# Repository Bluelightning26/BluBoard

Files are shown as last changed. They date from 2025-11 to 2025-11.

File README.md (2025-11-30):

# BluBoard
## A custom 75% keyboard!

### Key features: 
- MacOs Layout, 75% & separated arrow keys
- Two Rotary Encoders w/ Switches (Brightness + Volume)
- Cherry MX Brown Switches
- Simple Case with plop in design that keeps the black PCB visible while protecting the bottom and sides
- Specific parts used are documented in [BOM.md](BOM.md)

## Renders!!











### What I'd do differently next time
There were several sacrifices I had to make in the name of budgeting. Also, since this is my first full keyboard, I didn't want to overwhelm myself in the build process and avoided things that are difficult to solder. I am planning on making a v2 version of this keyboard after a few months of use, learning from the probable mistakes I made in design along the way

Nice features this would have:
- Wireless capability, BT + Dongle
- Acrylic Case
- RGB Backlit Keys
- 
(To be added to during build process along with when I use the board!)

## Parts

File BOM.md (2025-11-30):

| Item | Quantity | Total Cost | Link |
|---|---|---|---|
| Cherry MX Brown Switches | 90 | 31.61 | https://www.aliexpress.us/item/3256808812099705.html |
| Stabilizers | 4 + 1 | 3.55 | https://www.aliexpress.us/item/3256809701679392.html |
| Pi Pico 2 + Micro USB Cable | 1 | 14.99 | https://www.amazon.com/gp/product/B0F4W9J5CC/ |
| Rotary Encoder | 3 | 0.99 | https://www.aliexpress.us/item/3256807457768762.html |
| PCB | 1 | 57.49 | - |
| Case | 1 | - | - |
| Keycaps | - | 35.99 | https://www.amazon.com/gp/product/B0BVYQ7GQS/ |
| **Total inc shipping + tariffs:** | | **144.62** | |

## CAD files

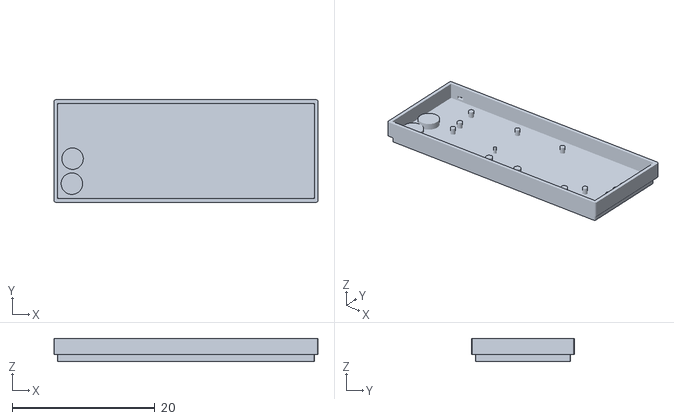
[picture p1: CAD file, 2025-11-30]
CAD/BluBoardCase.stl
37.0 x 14.4 x 3.25

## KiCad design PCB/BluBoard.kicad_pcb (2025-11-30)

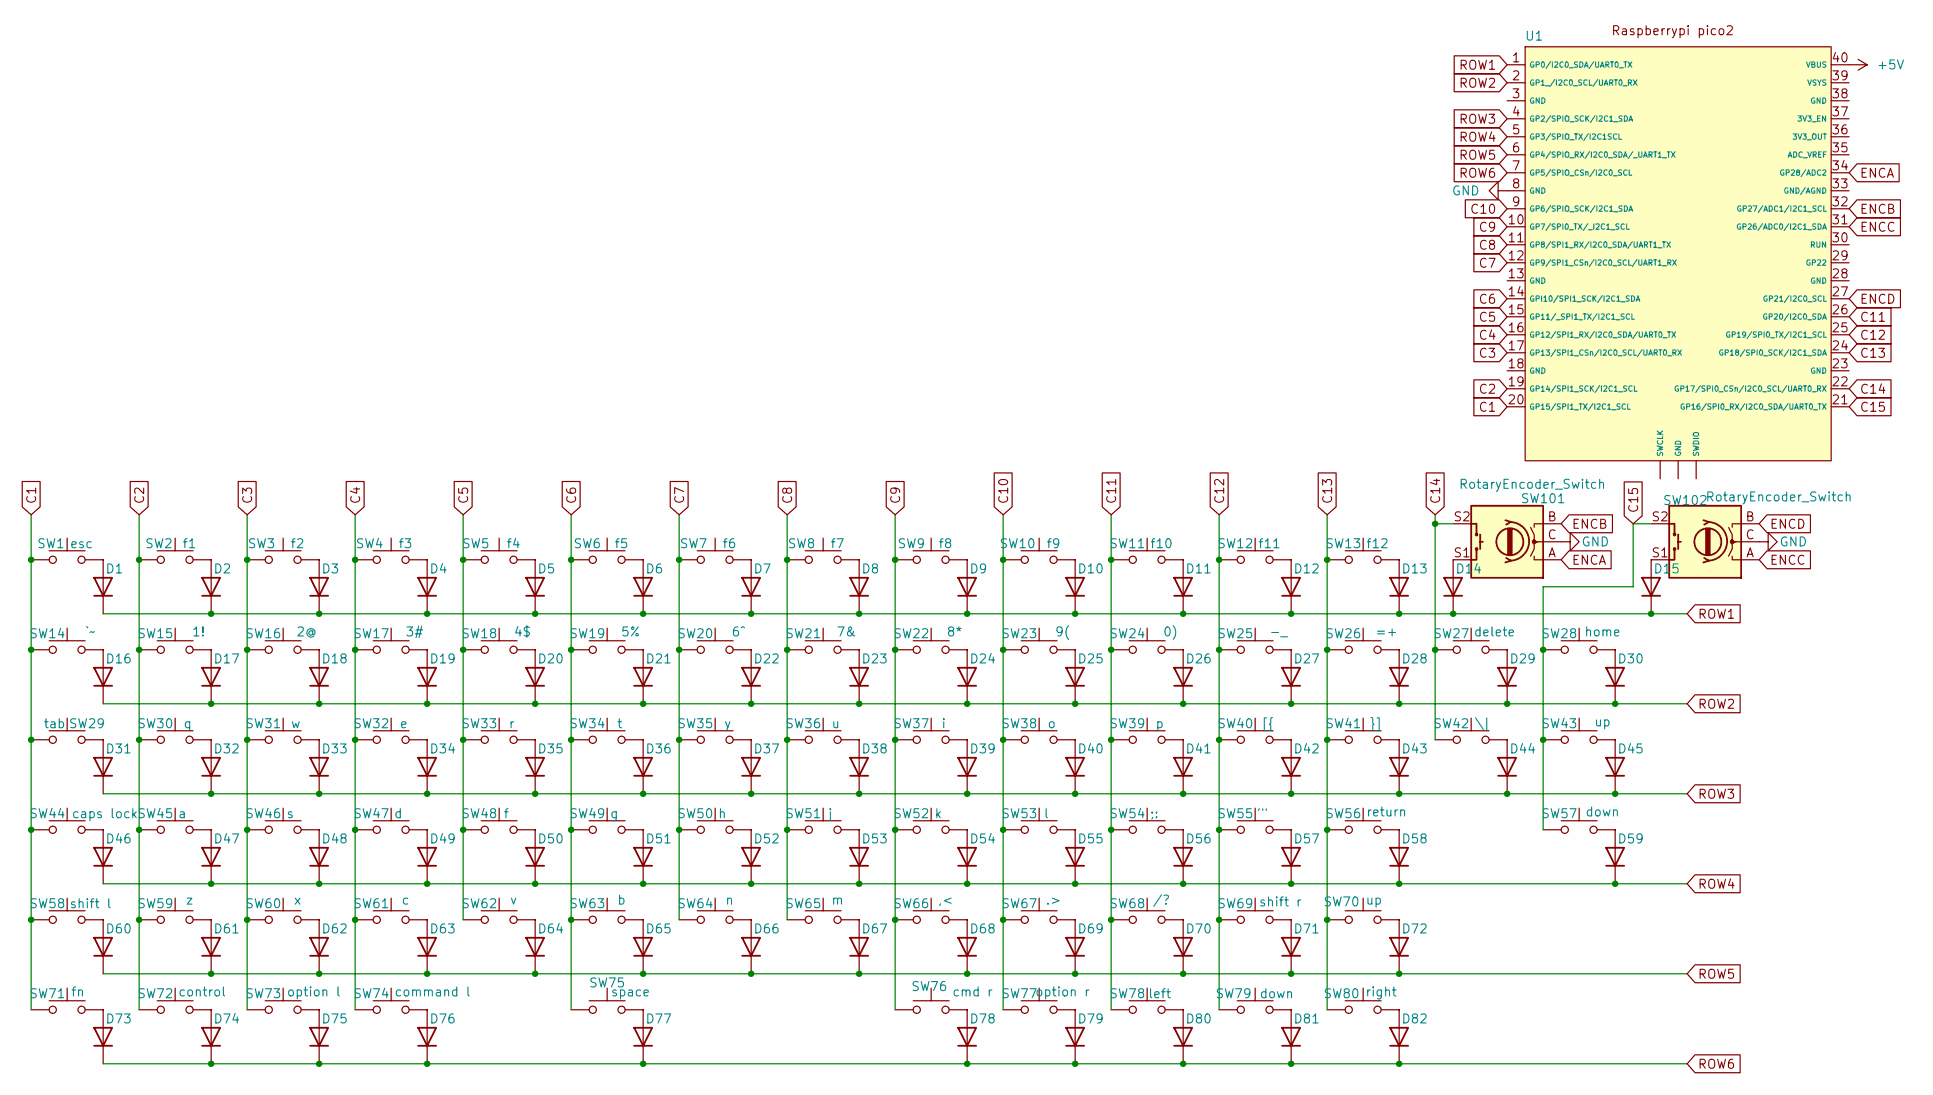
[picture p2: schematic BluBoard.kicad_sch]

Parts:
D1, D2, D3, D4, D5, D6, D7, D8, D9, D10, D11, D12, D13, D14, D15, D16, D17, D18, D19, D20, D21, D22, D23, D24, D25, D26, D27, D28, D29, D30, D31, D32, D33, D34, D35, D36, D37, D38, D39, D40, D41, D42, D43, D44, D45, D46, D47, D48, D49, D50, D51, D52, D53, D54, D55, D56, D57, D58, D59, D60, D61, D62, D63, D64, D65, D66, D67, D68, D69, D70, D71, D72, D73, D74, D75, D76, D77, D78, D79, D80, D81, D82: D; D_DO-35_SOD27_P7.62mm_Horizontal
SW1: esc; SW_Cherry_MX_1.00u_PCB
SW2: f1; SW_Cherry_MX_1.00u_PCB
SW3: f2; SW_Cherry_MX_1.00u_PCB
SW4: f3; SW_Cherry_MX_1.00u_PCB
SW5: f4; SW_Cherry_MX_1.00u_PCB
SW6: f5; SW_Cherry_MX_1.00u_PCB
SW7: f6; SW_Cherry_MX_1.00u_PCB
SW8: f7; SW_Cherry_MX_1.00u_PCB
SW9: f8; SW_Cherry_MX_1.00u_PCB
SW10: f9; SW_Cherry_MX_1.00u_PCB
SW11: f10; SW_Cherry_MX_1.00u_PCB
SW12: f11; SW_Cherry_MX_1.00u_PCB
SW13: f12; SW_Cherry_MX_1.00u_PCB
SW14: `~; SW_Cherry_MX_1.00u_PCB
SW15: 1!; SW_Cherry_MX_1.00u_PCB
SW16: 2@; SW_Cherry_MX_1.00u_PCB
SW17: 3#; SW_Cherry_MX_1.00u_PCB
SW18: 4$; SW_Cherry_MX_1.00u_PCB
SW19: 5%; SW_Cherry_MX_1.00u_PCB
SW20: 6^; SW_Cherry_MX_1.00u_PCB
SW21: 7&; SW_Cherry_MX_1.00u_PCB
SW22: 8*; SW_Cherry_MX_1.00u_PCB
SW23: 9(; SW_Cherry_MX_1.00u_PCB
SW24: 0); SW_Cherry_MX_1.00u_PCB
SW25: -_; SW_Cherry_MX_1.00u_PCB
SW26: =+; SW_Cherry_MX_1.00u_PCB
SW27: delete; SW_Cherry_MX_2.00u_PCB
SW28: home; SW_Cherry_MX_1.00u_PCB
SW29: tab; SW_Cherry_MX_1.50u_PCB
SW30: q; SW_Cherry_MX_1.00u_PCB
SW31: w; SW_Cherry_MX_1.00u_PCB
SW32: e; SW_Cherry_MX_1.00u_PCB
SW33: r; SW_Cherry_MX_1.00u_PCB
SW34: t; SW_Cherry_MX_1.00u_PCB
SW35: y; SW_Cherry_MX_1.00u_PCB
SW36: u; SW_Cherry_MX_1.00u_PCB
SW37: i; SW_Cherry_MX_1.00u_PCB
SW38: o; SW_Cherry_MX_1.00u_PCB
SW39: p; SW_Cherry_MX_1.00u_PCB
SW40: [{; SW_Cherry_MX_1.00u_PCB
SW41: }]; SW_Cherry_MX_1.00u_PCB
SW42: \|; SW_Cherry_MX_1.50u_PCB
SW43, SW70: up; SW_Cherry_MX_1.00u_PCB
SW44: caps lock; SW_Cherry_MX_1.75u_PCB
SW45: a; SW_Cherry_MX_1.00u_PCB
SW46: s; SW_Cherry_MX_1.00u_PCB
SW47: d; SW_Cherry_MX_1.00u_PCB
SW48: f; SW_Cherry_MX_1.00u_PCB
SW49: g; SW_Cherry_MX_1.00u_PCB
SW50: h; SW_Cherry_MX_1.00u_PCB
SW51: j; SW_Cherry_MX_1.00u_PCB
SW52: k; SW_Cherry_MX_1.00u_PCB
SW53: l; SW_Cherry_MX_1.00u_PCB
SW54: ;:; SW_Cherry_MX_1.00u_PCB
SW55: '"; SW_Cherry_MX_1.00u_PCB
SW56: return; SW_Cherry_MX_2.25u_PCB
SW57, SW79: down; SW_Cherry_MX_1.00u_PCB
SW58: shift l; SW_Cherry_MX_2.25u_PCB
SW59: z; SW_Cherry_MX_1.00u_PCB
SW60: x; SW_Cherry_MX_1.00u_PCB
SW61: c; SW_Cherry_MX_1.00u_PCB
SW62: v; SW_Cherry_MX_1.00u_PCB
SW63: b; SW_Cherry_MX_1.00u_PCB
SW64: n; SW_Cherry_MX_1.00u_PCB
SW65: m; SW_Cherry_MX_1.00u_PCB
SW66: ,<; SW_Cherry_MX_1.00u_PCB
SW67: .>; SW_Cherry_MX_1.00u_PCB
SW68: /?; SW_Cherry_MX_1.00u_PCB
SW69: shift r; SW_Cherry_MX_2.25u_PCB
SW71: fn; SW_Cherry_MX_1.00u_PCB
SW72: control; SW_Cherry_MX_1.00u_PCB
SW73: option l; SW_Cherry_MX_1.00u_PCB
SW74: command l; SW_Cherry_MX_1.25u_PCB
SW75: space; SW_Cherry_MX_6.25u_PCB
SW76: cmd r; SW_Cherry_MX_1.25u_PCB
SW77: option r; SW_Cherry_MX_1.00u_PCB
SW78: left; SW_Cherry_MX_1.00u_PCB
SW80: right; SW_Cherry_MX_1.00u_PCB
SW101, SW102: RotaryEncoder_Switch; RotaryEncoder_Alps_EC11E-Switch_Vertical_H20mm
U1: RaspberryPi_Pico_Common_THT

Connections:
+5V: U1.40 (VBUS)
C1: SW1.1, SW14.1, SW29.2, SW44.1, SW58.1, SW71.1, U1.20 (GP15/SPI1_TX/I2C1_SCL)
C2: SW2.1, SW15.1, SW30.1, SW45.1, SW59.1, SW72.1, U1.19 (GP14/SPI1_SCK/I2C1_SCL)
C3: SW3.1, SW16.1, SW31.1, SW46.1, SW60.1, SW73.1, U1.17 (GP13/SPI1_CSn/I2C0_SCL/UART0_RX)
C4: SW4.1, SW17.1, SW32.1, SW47.1, SW61.1, SW74.1, U1.16 (GP12/SPI1_RX/I2C0_SDA/UART0_TX)
C5: SW5.1, SW18.1, SW33.1, SW48.1, SW62.1, U1.15 (GP11/_SPI1_TX/I2C1_SCL)
C6: SW6.1, SW19.1, SW34.1, SW49.1, SW63.1, SW75.1, U1.14 (GPI10/SPI1_SCK/I2C1_SDA)
C7: SW7.1, SW20.1, SW35.1, SW50.1, SW64.1, U1.12 (GP9/SPI1_CSn/I2C0_SCL/UART1_RX)
C8: SW8.1, SW21.1, SW36.1, SW51.1, SW65.1, U1.11 (GP8/SPI1_RX/I2C0_SDA/UART1_TX)
C9: SW9.1, SW22.1, SW37.1, SW52.1, SW66.1, SW76.1, U1.10 (GP7/SPI0_TX/_I2C1_SCL)
C10: SW10.1, SW23.1, SW38.1, SW53.1, SW67.1, SW77.1, U1.9 (GP6/SPIO_SCK/I2C1_SDA)
C11: SW11.1, SW24.1, SW39.1, SW54.1, SW68.1, SW78.1, U1.26 (GP20/I2C0_SDA)
C12: SW12.1, SW25.1, SW40.1, SW55.1, SW69.1, SW79.1, U1.25 (GP19/SPI0_TX/I2C1_SCL)
C13: SW13.1, SW26.1, SW41.1, SW56.1, SW70.1, SW80.1, U1.24 (GP18/SPI0_SCK/I2C1_SDA)
C14: SW27.1, SW42.1, SW101.S2, U1.22 (GP17/SPI0_CSn/I2C0_SCL/UART0_RX)
C15: SW28.1, SW43.1, SW57.1, SW102.S2, U1.21 (GP16/SPI0_RX/I2C0_SDA/UART0_TX)
ENCA: SW101.A, U1.34 (GP28/ADC2)
ENCB: SW101.B, U1.32 (GP27/ADC1/I2C1_SCL)
ENCC: SW102.A, U1.31 (GP26/ADC0/I2C1_SDA)
ENCD: SW102.B, U1.27 (GP21/I2C0_SCL)
GND: SW101.C, SW102.C, U1.8 (GND)
unnamed: D1.2 (A), SW1.2
unnamed: D2.2 (A), SW2.2
unnamed: D3.2 (A), SW3.2
unnamed: D4.2 (A), SW4.2
unnamed: D5.2 (A), SW5.2
unnamed: D6.2 (A), SW6.2
unnamed: D7.2 (A), SW7.2
unnamed: D8.2 (A), SW8.2
unnamed: D9.2 (A), SW9.2
unnamed: D10.2 (A), SW10.2
unnamed: D11.2 (A), SW11.2
unnamed: D12.2 (A), SW12.2
unnamed: D13.2 (A), SW13.2
unnamed: D14.2 (A), SW101.S1
unnamed: D15.2 (A), SW102.S1
unnamed: D16.2 (A), SW14.2
unnamed: D17.2 (A), SW15.2
unnamed: D18.2 (A), SW16.2
unnamed: D19.2 (A), SW17.2
unnamed: D20.2 (A), SW18.2
unnamed: D21.2 (A), SW19.2
unnamed: D22.2 (A), SW20.2
unnamed: D23.2 (A), SW21.2
unnamed: D24.2 (A), SW22.2
unnamed: D25.2 (A), SW23.2
unnamed: D26.2 (A), SW24.2
unnamed: D27.2 (A), SW25.2
unnamed: D28.2 (A), SW26.2
unnamed: D29.2 (A), SW27.2
unnamed: D30.2 (A), SW28.2
unnamed: D31.2 (A), SW29.1
unnamed: D32.2 (A), SW30.2
unnamed: D33.2 (A), SW31.2
unnamed: D34.2 (A), SW32.2
unnamed: D35.2 (A), SW33.2
unnamed: D36.2 (A), SW34.2
unnamed: D37.2 (A), SW35.2
unnamed: D38.2 (A), SW36.2
unnamed: D39.2 (A), SW37.2
unnamed: D40.2 (A), SW38.2
unnamed: D41.2 (A), SW39.2
unnamed: D42.2 (A), SW40.2
unnamed: D43.2 (A), SW41.2
unnamed: D44.2 (A), SW42.2
unnamed: D45.2 (A), SW43.2
unnamed: D46.2 (A), SW44.2
unnamed: D47.2 (A), SW45.2
unnamed: D48.2 (A), SW46.2
unnamed: D49.2 (A), SW47.2
unnamed: D50.2 (A), SW48.2
unnamed: D51.2 (A), SW49.2
unnamed: D52.2 (A), SW50.2
unnamed: D53.2 (A), SW51.2
unnamed: D54.2 (A), SW52.2
unnamed: D55.2 (A), SW53.2
unnamed: D56.2 (A), SW54.2
unnamed: D57.2 (A), SW55.2
unnamed: D58.2 (A), SW56.2
unnamed: D59.2 (A), SW57.2
unnamed: D60.2 (A), SW58.2
unnamed: D61.2 (A), SW59.2
unnamed: D62.2 (A), SW60.2
unnamed: D63.2 (A), SW61.2
unnamed: D64.2 (A), SW62.2
unnamed: D65.2 (A), SW63.2
unnamed: D66.2 (A), SW64.2
unnamed: D67.2 (A), SW65.2
unnamed: D68.2 (A), SW66.2
unnamed: D69.2 (A), SW67.2
unnamed: D70.2 (A), SW68.2
unnamed: D71.2 (A), SW69.2
unnamed: D72.2 (A), SW70.2
unnamed: D73.2 (A), SW71.2
unnamed: D74.2 (A), SW72.2
unnamed: D75.2 (A), SW73.2
unnamed: D76.2 (A), SW74.2
unnamed: D77.2 (A), SW75.2
unnamed: D78.2 (A), SW76.2
unnamed: D79.2 (A), SW77.2
unnamed: D80.2 (A), SW78.2
unnamed: D81.2 (A), SW79.2
unnamed: D82.2 (A), SW80.2
ROW1: D1.1 (K), D2.1 (K), D3.1 (K), D4.1 (K), D5.1 (K), D6.1 (K), D7.1 (K), D8.1 (K), D9.1 (K), D10.1 (K), D11.1 (K), D12.1 (K), D13.1 (K), D14.1 (K), D15.1 (K), U1.1 (GP0/I2C0_SDA/UART0_TX)
ROW2: D16.1 (K), D17.1 (K), D18.1 (K), D19.1 (K), D20.1 (K), D21.1 (K), D22.1 (K), D23.1 (K), D24.1 (K), D25.1 (K), D26.1 (K), D27.1 (K), D28.1 (K), D29.1 (K), D30.1 (K), U1.2 (GP1_/I2C0_SCL/UART0_RX)
ROW3: D31.1 (K), D32.1 (K), D33.1 (K), D34.1 (K), D35.1 (K), D36.1 (K), D37.1 (K), D38.1 (K), D39.1 (K), D40.1 (K), D41.1 (K), D42.1 (K), D43.1 (K), D44.1 (K), D45.1 (K), U1.4 (GP2/SPIO_SCK/I2C1_SDA)
ROW4: D46.1 (K), D47.1 (K), D48.1 (K), D49.1 (K), D50.1 (K), D51.1 (K), D52.1 (K), D53.1 (K), D54.1 (K), D55.1 (K), D56.1 (K), D57.1 (K), D58.1 (K), D59.1 (K), U1.5 (GP3/SPIO_TX/I2C1SCL)
ROW5: D60.1 (K), D61.1 (K), D62.1 (K), D63.1 (K), D64.1 (K), D65.1 (K), D66.1 (K), D67.1 (K), D68.1 (K), D69.1 (K), D70.1 (K), D71.1 (K), D72.1 (K), U1.6 (GP4/SPIO_RX/I2C0_SDA/_UART1_TX)
ROW6: D73.1 (K), D74.1 (K), D75.1 (K), D76.1 (K), D77.1 (K), D78.1 (K), D79.1 (K), D80.1 (K), D81.1 (K), D82.1 (K), U1.7 (GP5/SPIO_CSn/I2C0_SCL)

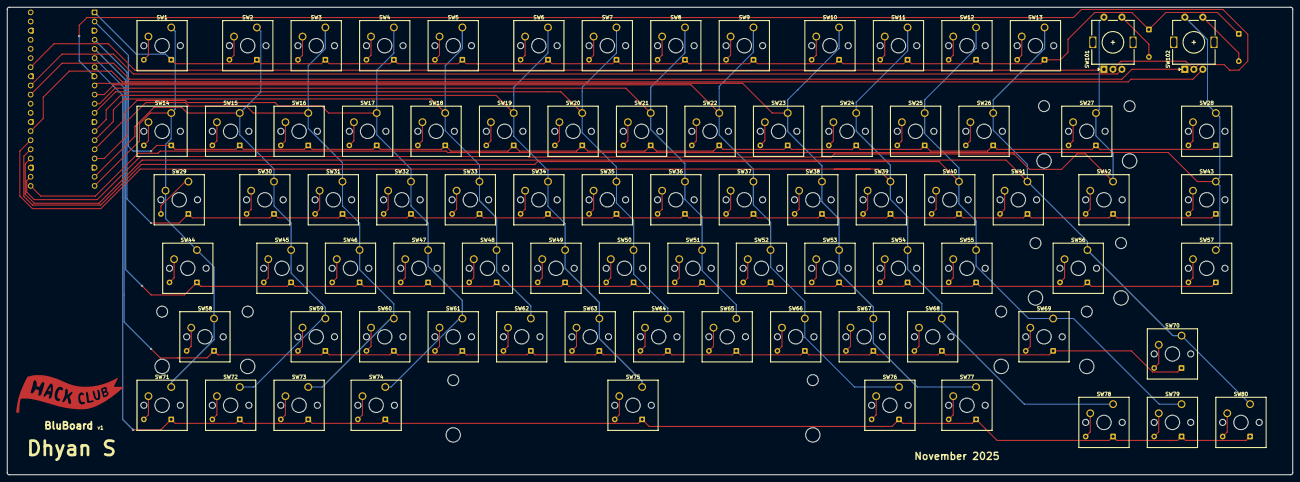
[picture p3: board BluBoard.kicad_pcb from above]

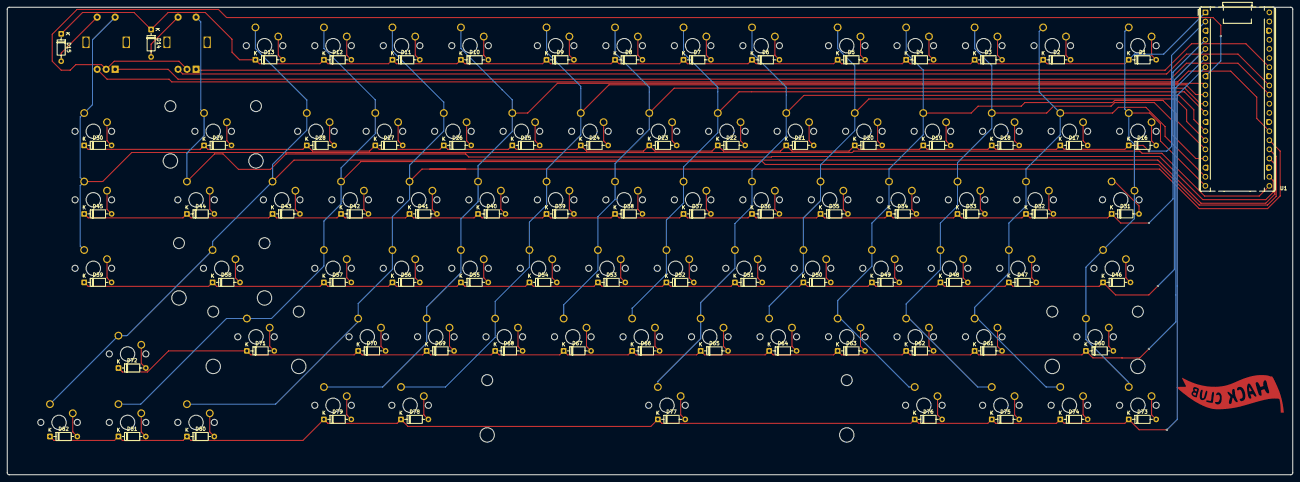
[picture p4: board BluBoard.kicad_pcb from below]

Board: 2 copper layers, 357.5 x 130.0 mm, 165 parts (83 on the bottom side), 108 nets.

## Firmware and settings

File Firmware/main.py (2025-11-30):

import board
import digitalio
from kmk.kmk_keyboard import KMKKeyboard
from kmk.scanners import DiodeOrientation
from kmk.keys import KC
from kmk.modules.macros import Macros
from kmk.modules.mouse_keys import MouseKeys
from kmk.modules.encoder import EncoderHandler
from kmk.extensions.media_keys import MediaKeys

# Create the keyboard object
keyboard = KMKKeyboard()

# Add modules
macros = Macros()
keyboard.modules.append(macros)

mouse = MouseKeys()
keyboard.modules.append(mouse)

media_keys = MediaKeys()
keyboard.extensions.append(media_keys)

encoder_handler = EncoderHandler()
keyboard.modules.append(encoder_handler)

# Define the row and column pins
keyboard.row_pins = (
    board.GP0,  # R1
    board.GP1,
    board.GP2,
    board.GP3,
    board.GP4,  # R5
    board.GP5,
)

keyboard.col_pins = (
    board.GP15,  # C1
    board.GP14,
    board.GP13,
    board.GP12,
    board.GP11,
    board.GP10,
    board.GP9,  # C7
    board.GP8,
    board.GP7,
    board.GP6,  # C10
    board.GP20,
    board.GP19,
    board.GP18,
    board.GP17,
    board.GP16,  # C15
)

keyboard.diode_orientation = DiodeOrientation.COL2ROW

# Define keys with your specific layout and widths
_______ = KC.TRNS
xxxxxxx = KC.NO

# Keymap based on your JSON input
keyboard.keymap = [
    # Base (Layer 0)
    [
        KC.ESC,   KC.F1,   KC.F2, KC.F3,   KC.F4, KC.F5, KC.F6,    KC.F7, KC.F8, KC.F9,    KC.F10,  KC.F11,    KC.F12,   KC.NLCK,  KC.SLCK, KC.INS,   KC.MUTE,
        KC.GRAVE, KC.N1,   KC.N2, KC.N3,   KC.N4, KC.N5, KC.N6,    KC.N7, KC.N8, KC.N9,    KC.N0,   KC.MINUS,  KC.EQUAL, xxxxxxx,  KC.BSPC, KC.HOME,  xxxxxxx,
        KC.TAB,   xxxxxxx, KC.Q,  KC.W,    KC.E,  KC.R,  KC.T,     KC.Y,  KC.U,  KC.I,     KC.O,    KC.P,      KC.LBRC,  KC.RBRC,  KC.BSLS, KC.PGUP,  xxxxxxx,
        KC.CAPS,  xxxxxxx, KC.A,  KC.S,    KC.D,  KC.F,  KC.G,     KC.H,  KC.J,  KC.K,     KC.L,    KC.SCOLON, KC.QUOTE, KC.ENTER, KC.NO,   KC.PGDN,  xxxxxxx,
        xxxxxxx,  KC.LSFT, KC.Z,  KC.X,    KC.C,  KC.V,  KC.B,     KC.N,  KC.M,  KC.COMMA, KC.DOT,  KC.SLASH,  xxxxxxx,  KC.RSFT,  KC.UP,   KC.END,   xxxxxxx,
        KC.LCTRL, KC.LGUI, KC.NO, KC.LALT, xxxxxxx, xxxxxxx, KC.SPACE, xxxxxxx, xxxxxxx, xxxxxxx, KC.RALT, KC.MO(1), KC.RCTRL, KC.LEFT,  KC.DOWN, KC.RIGHT, xxxxxxx,
    ],

    # Fn (Layer 1)
    [
        xxxxxxx, KC.MUTE, KC.VOLD, KC.VOLU, KC.MPRV, KC.MPLY, KC.MNXT, xxxxxxx, xxxxxxx, xxxxxxx, xxxxxxx, KC.BRID, KC.BRIU, KC.PSCR, KC.PAUS, KC.DEL,  _______,
        xxxxxxx, KC.LSFT, KC.N1, KC.N2,   KC.N3,  KC.N4,  KC.N5,     KC.N6,  KC.N7,  KC.N8,   KC.N9,
